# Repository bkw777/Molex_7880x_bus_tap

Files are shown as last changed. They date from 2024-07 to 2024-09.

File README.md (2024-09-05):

# Molex 7880x BUS TAP
Bus tap to fit between a Molex 78805 socket and a chip in a Molex 78802 carrier

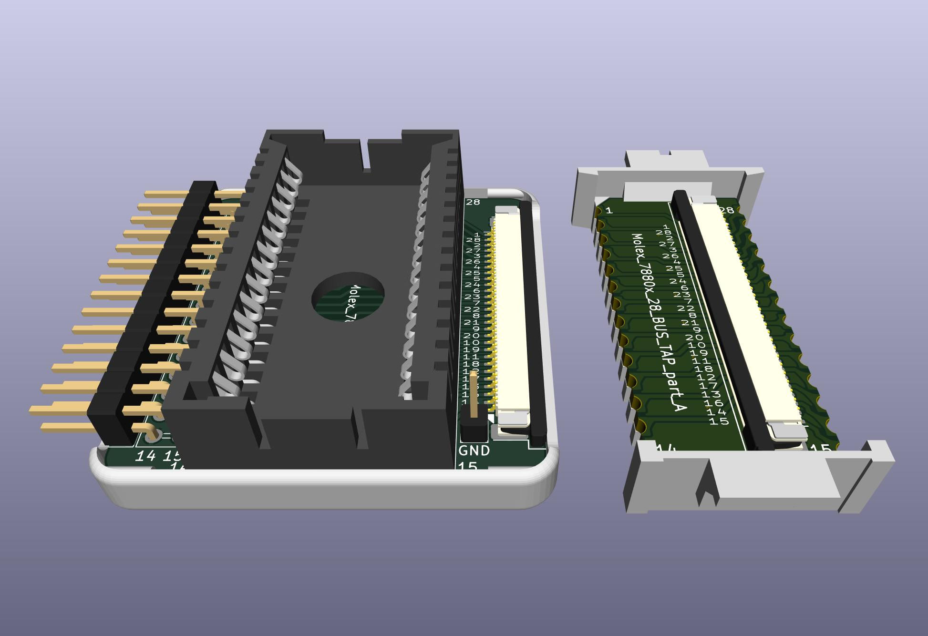
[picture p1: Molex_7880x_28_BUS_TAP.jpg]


More pics: https://photos.app.goo.gl/PHQ1rTQFpPRF6NSh8

Provides a connection point for a logic analyzer or oscilloscope to tap the bus between a Molex 78805 socket and a mating Molex 78802 carrier module that would normally be in the socket.

## Parts

Carrier for the small PCB: https://github.com/bkw777/Molex78802_Module/blob/master/Carrier/Molex78802_PCB_28.stl  
&nbsp;&nbsp;Some places to buy from. Select Material: Nylon, Process: SLS or MJF  
&nbsp;&nbsp;https://www.sculpteo.com/en/print/molex78802_pcb_28-18/nC7YgK6X  
&nbsp;&nbsp;https://www.pcbway.com/project/shareproject/Molex_7880x_28_PCB_Carrier_9419cd9c.html

Housing for the large PCB: [CASE/Molex_7880x_bus_tap_cover.stl](CASE/Molex_7880x_bus_tap_cover.stl)  
&nbsp;&nbsp;This one can be FDM printed.

FFC connector (x2): https://www.digikey.com/en/products/detail/amphenol-cs-fci/F52R-1A7H1-11028/11564624

FFC cable - 4" gold - Molex 0150390449 : https://www.digikey.com/en/products/detail/molex/0150390449/11581605  
FFC Cable - 6" gold - Molex 0150390453 : https://www.digikey.com/en/products/detail/molex/0150390453/11581883  
Other FFC Cables in other lengths, copper weight, plating options: https://www.digikey.com/short/pqq5pd04  

Molex 78805 socket: These are no longer made. Find me on the M100 mail list. I have some and will sell them one at a time until gone.  

Other possible solutions for the socket:  
* Once in a great while they do turn up on ebay or other places on-line:  
  https://www.dhgate.com/product/for-molex-dip28p-ic-chip-socket-silver-plated/835617844.html  
  https://www.ebay.com/itm/153988317907  
  Search "molex ic socket" and then ignore all the normal dip sockets.  
  Other search terms: 8878 28S, A78805-0518, A78805-0918, 15-29-9282, 15-41-2283  
  Or any other part number from here: https://github.com/bkw777/Molex78802_Module/blob/master/references/015299282_sd_corrected.pdf  
  Particularly detail-1, detail-10, detail-11 as those ones all have key slots at positions 1,5,9. The peg positions on the bottom don't matter because they can just be cut off.  
  (Or maybe I'll update the pcb to include drill holes in all 8 peg positions. Really any version of the socket would be better than nothing if you found any at all, just cut the missing key slots if needed.)  
* DIP-28 (or more) test clip and a standard dip-28 socket or male pin headers to connect the wires.  
  When searching for a test clip, make sure it opens wide enough for 600 mill / aka 0.6" wide dip-28, not just 300 mil.  
  https://duckduckgo.com/?t=h_&q=test+clip+dip+28+32+40+600+0.6
* Solder long wire-wrap pins in place of the socket and wedge the module between the pins.  
  https://www.digikey.com/en/products/detail/samtec-inc/ZW-16-15-F-S-225-175/6614101  
  The width of the module is a little wider than the width of the pins, so the pins would need to be bent, or change the PCB to provide a footprint with just the right spacing.  
* Change the PCB to use 2 of these: https://www.digikey.com/en/products/detail/samtec-inc/SIR1-15-L-S/10218718  
* Change the PCB to use these: https://lectronz.com/products/flexypin-pack-of-100

TODO: Design a socket that can be printed and just needs plain wire for the contacts.

Machines with this socket:  
* TRS-80/TANDY Model 100, 102, 200, 600
* Kyotronic KC-85
* Epson PX-4, PX-8
* Intermec 9440, Telexon 710, and similar hand-held teriminals
* Allen-Bradley SLC 500 programmable controllers

Cable notes:  
4" is long enough to reach out from under the nearest side to the socket on all machines.  
6" is long enough to reach the left instead of the front on a Model 200.  
8" is long enough to reach the back on a Model 100, and does still work, but might be getting marginal at this length.  
10" untested  
12" does not work

# PINOUTS
<table>
<tr> <th colspan=4>TANDY 100/102/200</th> <th width=100></th> <th colspan=4>TANDY 600 / Epson PX-4/8<br>(STANDARD MASK ROM)</th> </tr>
<tr> <td>VCC</td><td>1</td><td>28</td><td>A14</td> <td></td>  <td>NC</td><td>1</td><td>28</td><td>VCC</td> </tr>
<tr> <td>A10</td><td></td><td></td><td>/CS</td> <td></td>  <td>A12</td><td></td><td></td><td>A14</td> </tr>
<tr> <td>A7</td><td></td><td></td><td>A8</td> <td></td>  <td>A7</td><td></td><td></td><td>A13</td> </tr>
<tr> <td>A6</td><td></td><td></td><td>A9</td> <td></td>  <td>A6</td><td></td><td></td><td>A8</td> </tr>
<tr> <td>A5</td><td></td><td></td><td>A12</td> <td></td>  <td>A5</td><td></td><td></td><td>A9</td> </tr>
<tr> <td>A4</td><td></td><td></td><td>ALE</td> <td></td>  <td>A4</td><td></td><td></td><td>A11</td> </tr>
<tr> <td>A3</td><td></td><td></td><td>A13</td> <td></td>  <td>A3</td><td></td><td></td><td>/OE</td> </tr>
<tr> <td>A2</td><td></td><td></td><td>/OE</td> <td></td>  <td>A2</td><td></td><td></td><td>A10</td> </tr>
<tr> <td>A1</td><td></td><td></td><td>A11</td> <td></td>  <td>A1</td><td></td><td></td><td>/CS</td> </tr>
<tr> <td>A0</td><td></td><td></td><td>AD7</td> <td></td>  <td>A0</td><td></td><td></td><td>D7</td> </tr>
<tr> <td>AD0</td><td></td><td></td><td>AD6</td> <td></td>  <td>D0</td><td></td><td></td><td>D6</td> </tr>
<tr> <td>AD1</td><td></td><td></td><td>AD5</td> <td></td>  <td>D1</td><td></td><td></td><td>D5</td> </tr>
<tr> <td>AD2</td><td></td><td></td><td>AD4</td> <td></td>  <td>D2</td><td></td><td></td><td>D4</td> </tr>

<tr> <td>GND</td><td>14</td><td>15</td><td>AD3</td> <td></td>  <td>GND</td><td>14</td><td>15</td><td>D3</td> </tr>
</table>
<!--
| | | | | | | | | | |
| --- | --- | --- | --- | --- | --- | --- | --- | --- | --- |
| VCC | 1 | 28  | A14 | | | NC  | 1 | 28  | VCC |
| A10 | | | /CS | | | A12 | | | A14 |
| A7  | | | A8  | | | A7  | | | A13 |
| A6  | | | A9  | | | A6  | | | A8  |
| A5  | | | A12 | | | A5  | | | A9  |
| A4  | | | ALE | | | A4  | | | A11 |
| A3  | | | A13 | | | A3  | | | /OE |
| A2  | | | /OE | | | A2  | | | A10 |
| A1  | | | A11 | | | A1  | | | /CS |
| A0  | | | AD7 | | | A0  | | | D7  |
| AD0 | | | AD6 | | | D0  | | | D6  |
| AD1 | | | AD5 | | | D1  | | | D5  |
| AD2 | | | AD4 | | | D2  | | | D4  |
| GND | 14  | 15  | AD3 | | | GND | 14  | 15  | D3  |
-->

# GND pins work-around
This thing could really use a bunch more GND pins, both for logic analyzer probes and for a place to clip oscilloscope probe alligator clips.
Currently there is only the single GND pin which is pin 14.

For now a simple work-around that provides both extra pins for logic analyzer probe grounds and a perfect place for a scope probe alligator clip, is just a piece of single row male pin header with a wire soldered to bridge all of the posts, and a single short female-female dupont jumper to connect to the single gnd pin.

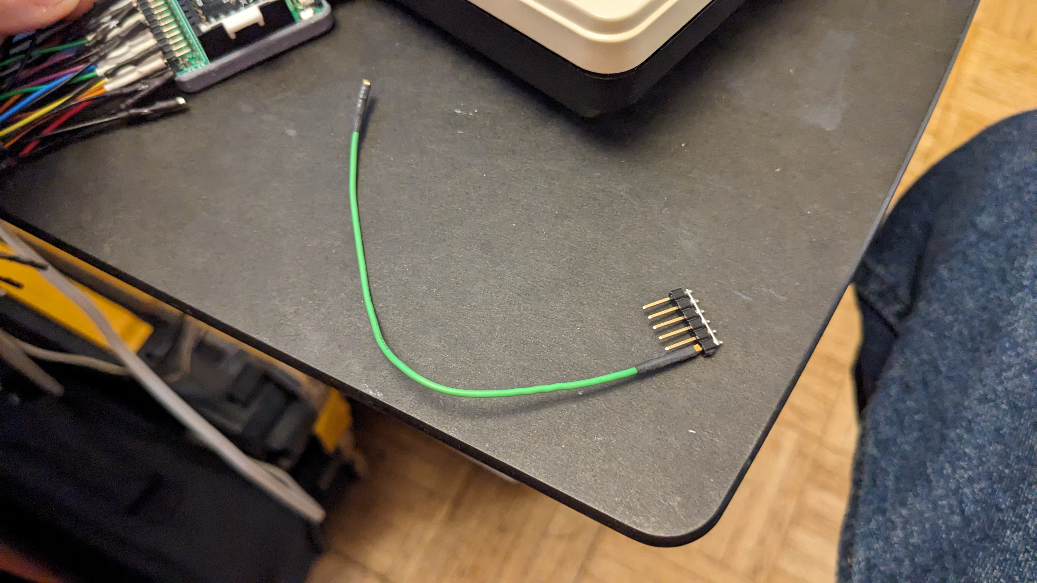
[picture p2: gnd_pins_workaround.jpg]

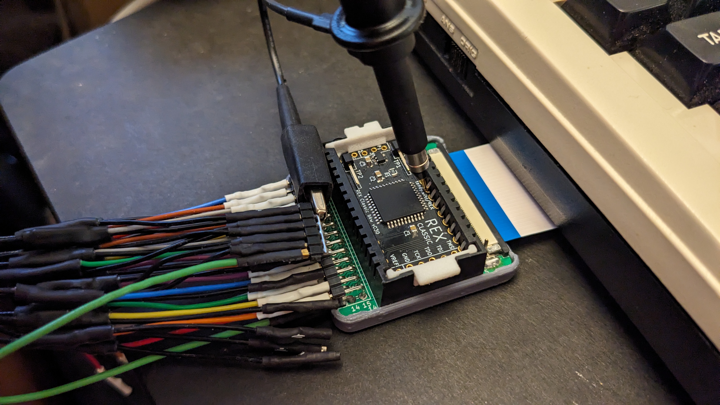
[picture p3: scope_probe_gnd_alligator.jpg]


# Related
http://tandy.wiki/Molex78802_Module  
https://github.com/bkw777/M4ROM  
http://tandy.wiki/Teeprom  
http://tandy.wiki/REX

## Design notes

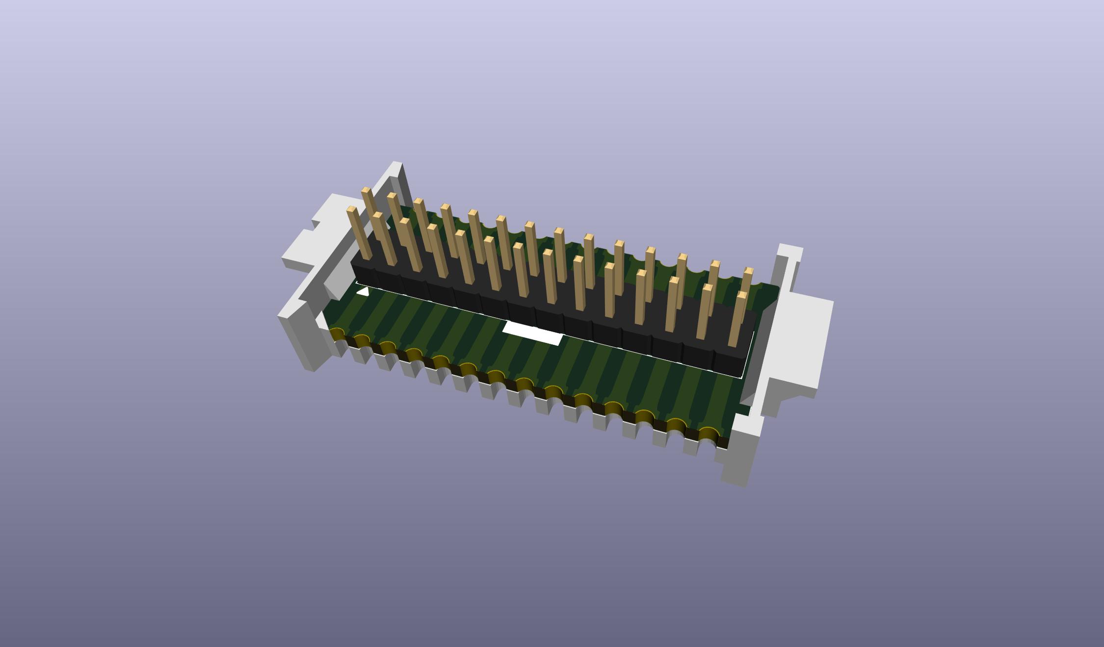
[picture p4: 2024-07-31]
PCB/out/Molex78802_PCB_28_breakout.jpg

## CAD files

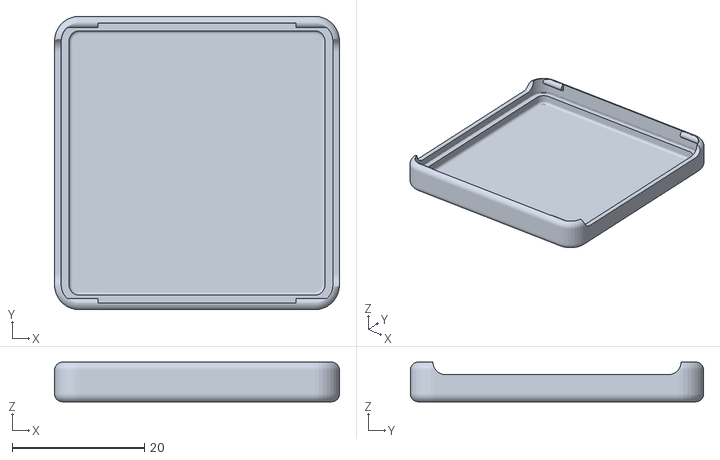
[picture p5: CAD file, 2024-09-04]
CASE/Molex_7880x_bus_tap_cover.stl
43.0 x 44.3 x 5.98

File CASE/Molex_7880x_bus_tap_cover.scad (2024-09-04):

/*
 * Enclosure for Molex_7880x_bus_tap
 */

// true = taller cover with clips at the corners
// false = shorter simpler cover that needs glue or adhesive tape
with_clips = true;

mil = 0.0254;

pcb_w = 1600*mil;
pcb_d = 1650*mil;
pcb_h = 1.6;
pcb_r = 100*mil;

molex_w = 940*mil;
//ffc_w = 6;      // ffc connector width
//ffc_d = 36;     // ffc connector depth
//ph_w = 300*mil; // pin header width
ph_d = 1400*mil;  // pin header depth

bottom_h = 2;

wt = 1;   // wall thickness
cr = 0.5; // corner/fillet radius

//mw = 0.8; // minimum allowed wall thickness
fc = 0.2; // fitment clearance
e = 0.1;  // epsilon (overlap/overcut)
//$fa = 2;
//$fs = 0.1;
$fn = 36;


ih = pcb_h+bottom_h;
or = fc+wt;
ow = or+pcb_w+or;
od = or+pcb_d+or;
oh = or+ih+or;

// =================================================================

use <inc/handy.scad>

module fit_parts() {
  import("inc/pcb.stl");
}

module body () {
     difference() {

      // add
      // exterior
      translate([0,0,oh/2-bottom_h-wt]) rounded_cube(w=ow,d=od,h=oh,rh=pcb_r+or,rv=or,t=0);

      // cut
      union () {
        // top
        if (!with_clips) translate([0,0,oh/2+pcb_h-fc]) cube([e+ow+e,e+od+e,oh],center=true);
        // pcb
        translate([0,0,oh/2-fc]) rounded_cube(w=fc+pcb_w+fc,d=fc+pcb_d+fc,h=oh,rh=pcb_r+fc,rv=fc,t=0);
        // bottom
        translate([0,0,oh/2-bottom_h]) rounded_cube(w=pcb_w-wt-wt,d=pcb_d-wt-wt,h=oh,rh=pcb_r-wt,rv=cr,t=0);

        if (with_clips) {
          r = 75*mil;
          translate([0,0,oh-r]) rounded_cube(w=e+r+ow+r+e,d=ph_d+r,h=oh,rh=r,rv=r,t=0);
        }

        // debugging cutaway
        //translate([0,od/4+e/2,oh/2-bottom_h-wt-e]) cube([e+ow+e,od/2+e,e+oh+e],center=true);

      }
    }

    if (with_clips) {
      cs = 3;
      cd = oh/2-pcb_h-0.05;
      cl = ow/2-molex_w/2-cs;
      hr = pcb_r+fc;
      mirror_copy([0,1,0])
        mirror_copy([1,0,0])
          intersection () {
            translate([molex_w/2+cs,pcb_d/2+fc,cd/2+pcb_h])
              rotate([0,90,0])
                cylinder(d=cd,h=cl);
      
            translate([pcb_w/2-cl-hr+fc+e,pcb_d/2-hr*2+fc+e,0])
              hull() {
                translate([cl,hr,0]) cylinder(r=hr,h=oh);
                cube([cl,hr*2,oh]);
              }
         }
    }

}

// =================================================================

%fit_parts();
body();

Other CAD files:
CASE/inc/handy.scad

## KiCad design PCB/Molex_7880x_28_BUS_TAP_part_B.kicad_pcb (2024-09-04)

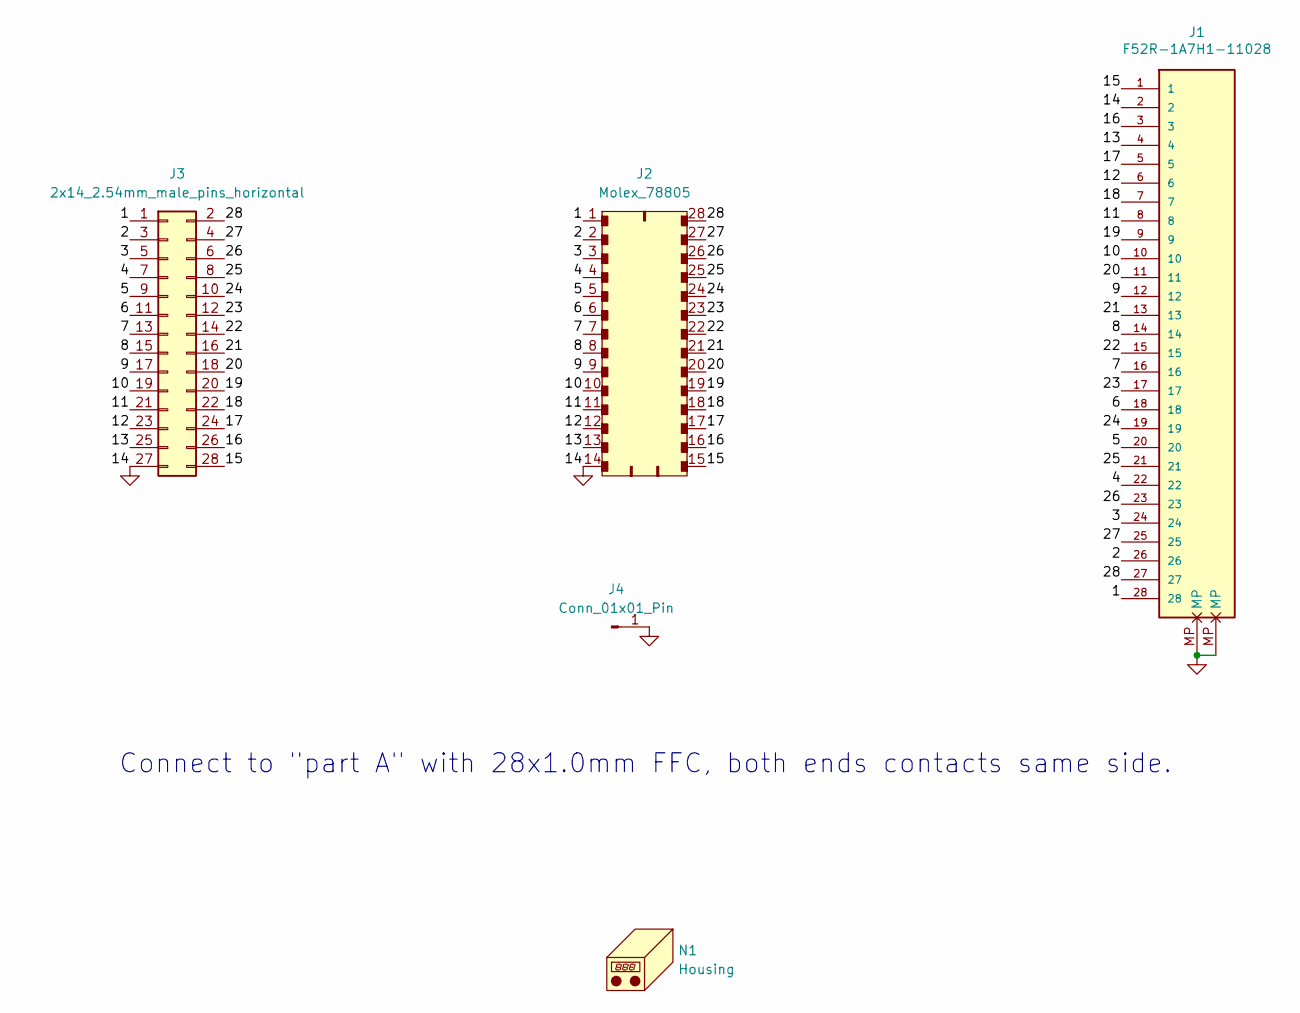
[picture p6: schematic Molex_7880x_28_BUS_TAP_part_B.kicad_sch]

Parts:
J1: F52R-1A7H1-11028; PARTREV A
J2: Molex_78805
J3: 2x14_2.54mm_male_pins_horizontal; PinHeader_2x14_P2.54mm_LH
J4: Conn_01x01_Pin; PinHeader_1x1_P2.54mm
N1: Housing; Molex_7880x_bus_tap_cover

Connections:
/1: J1.28, J2.1, J3.1
/2: J1.26, J2.2, J3.3
/3: J1.24, J2.3, J3.5
/4: J1.22, J2.4, J3.7
/5: J1.20, J2.5, J3.9
/6: J1.18, J2.6, J3.11
/7: J1.16, J2.7, J3.13
/8: J1.14, J2.8, J3.15
/9: J1.12, J2.9, J3.17
/10: J1.10, J2.10, J3.19
/11: J1.8, J2.11, J3.21
/12: J1.6, J2.12, J3.23
/13: J1.4, J2.13, J3.25
/15: J1.1, J2.15, J3.28
/16: J1.3, J2.16, J3.26
/17: J1.5, J2.17, J3.24
/18: J1.7, J2.18, J3.22
/19: J1.9, J2.19, J3.20
/20: J1.11, J2.20, J3.18
/21: J1.13, J2.21, J3.16
/22: J1.15, J2.22, J3.14
/23: J1.17, J2.23, J3.12
/24: J1.19, J2.24, J3.10
/25: J1.21, J2.25, J3.8
/26: J1.23, J2.26, J3.6
/27: J1.25, J2.27, J3.4
/28: J1.27, J2.28, J3.2
GND: J1.2, J1.MP, J2.14, J3.27, J4.1

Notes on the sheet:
Connect to "part A" with 28x1.0mm FFC, both ends contacts same side.

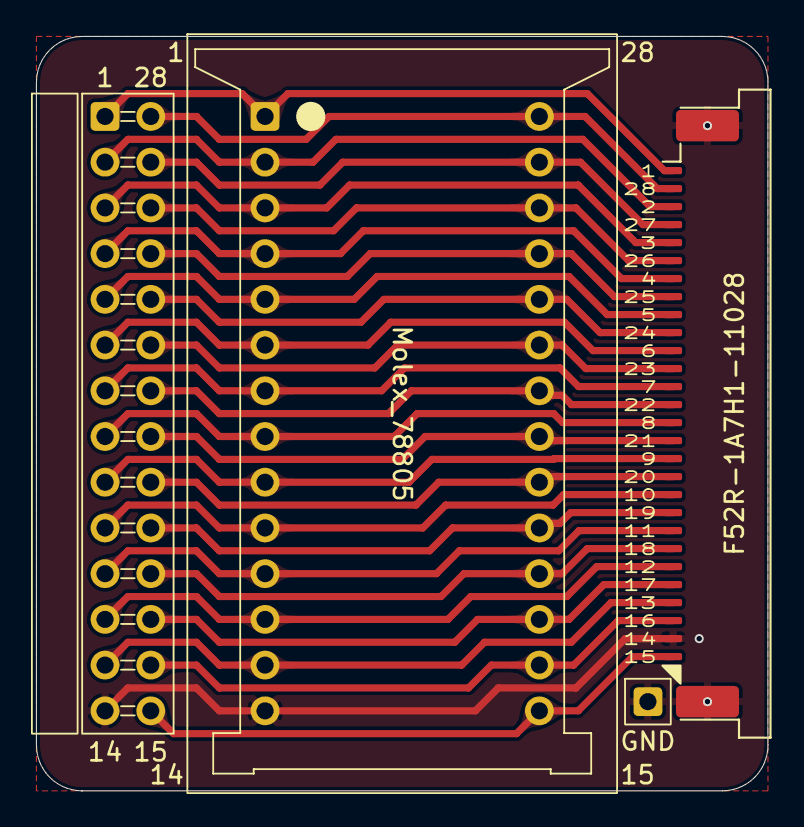
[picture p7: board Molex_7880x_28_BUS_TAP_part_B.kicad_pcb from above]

Board: 2 copper layers, 40.6 x 41.9 mm, 5 parts (0 on the bottom side), 28 nets.

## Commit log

2024-09-04 add housing, add extra gnd pin
    [Molex_7880x_28_BUS_TAP_part_A.kicad_pcb, Molex_7880x_28_BUS_TAP_part_B.kicad_pcb, Molex_7880x_28_BUS_TAP_part_B.kicad_sch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]
2024-09-05 readme about extra gnd hookups
2024-09-05 readme more help about special socket

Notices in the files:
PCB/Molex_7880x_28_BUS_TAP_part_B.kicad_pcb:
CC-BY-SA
